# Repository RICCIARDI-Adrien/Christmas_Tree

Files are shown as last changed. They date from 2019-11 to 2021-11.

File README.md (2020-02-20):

# Christmas tree

A lighted Christmas tree with shiny fairy lights and star.  

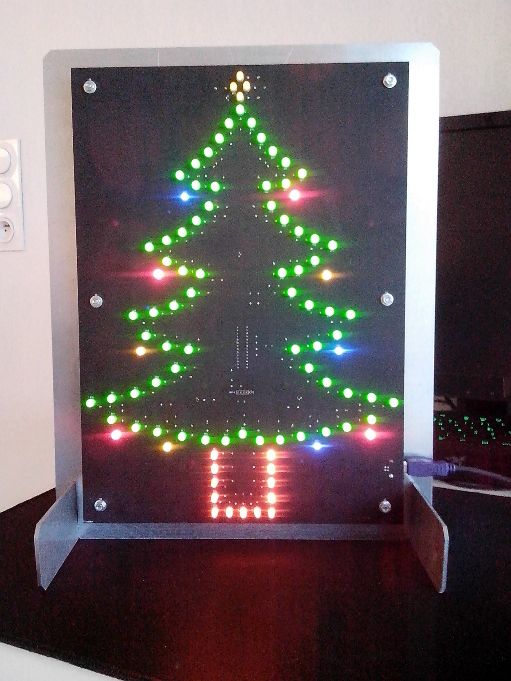
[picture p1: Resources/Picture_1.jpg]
Christmas tree picture 1

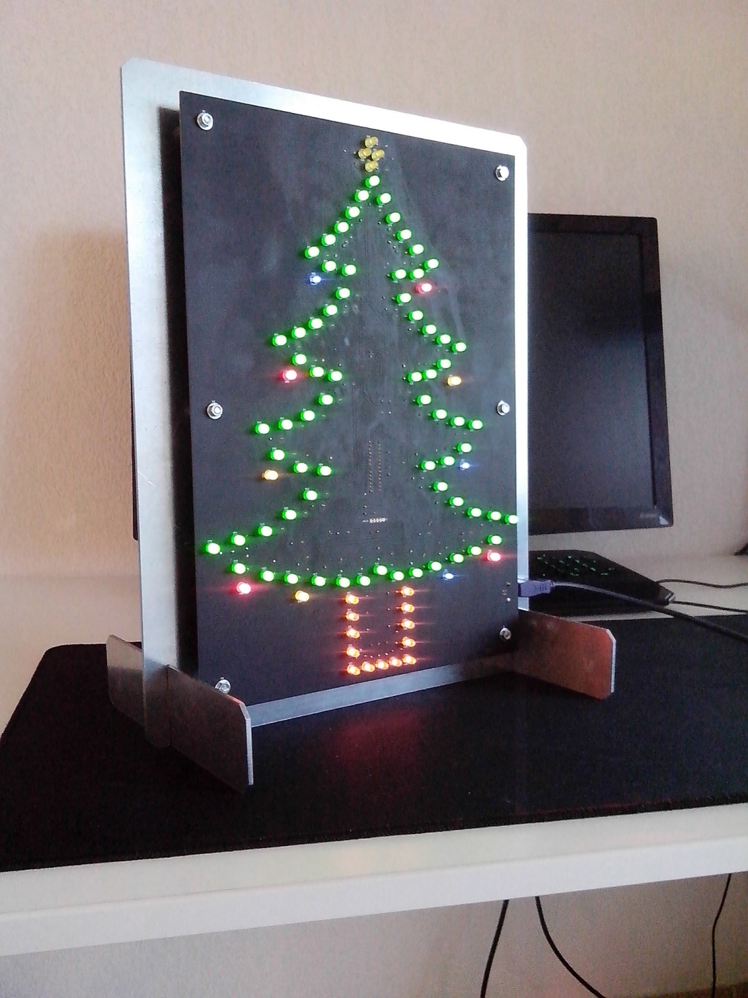
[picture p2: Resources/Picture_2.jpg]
Christmas tree picture 2


Here are all needed parts to build the Christmas tree :  
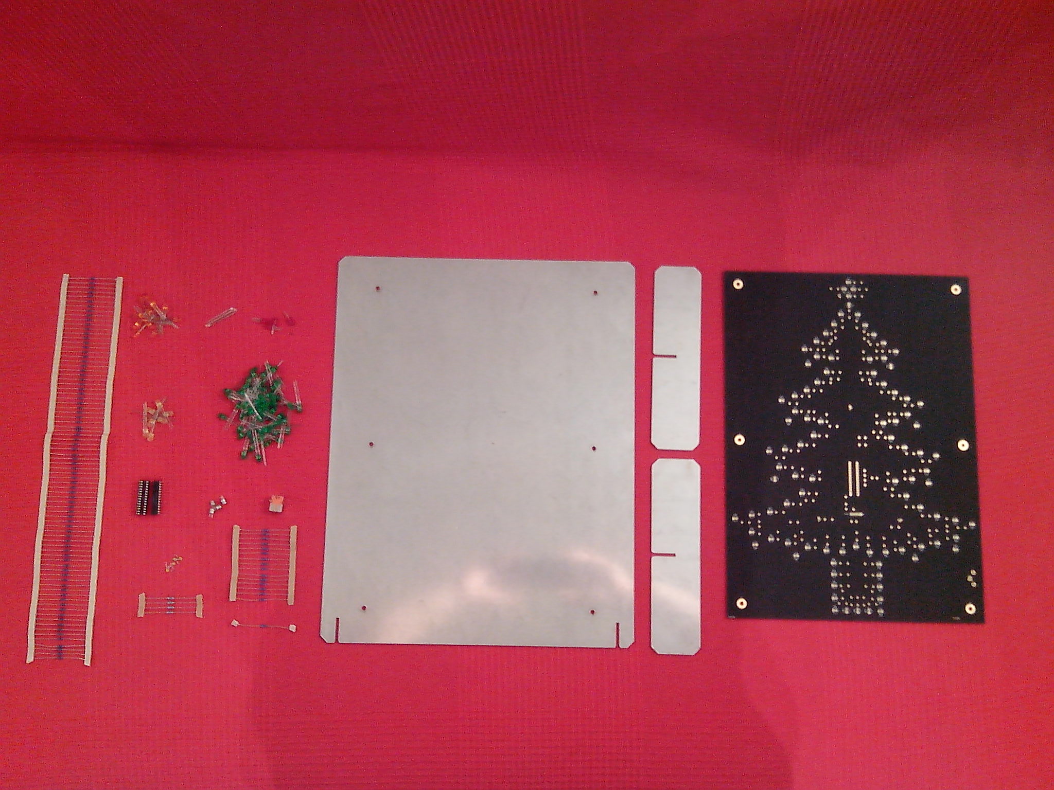
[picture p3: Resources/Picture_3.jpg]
Christmas tree picture 3


## Hardware

Board has been designed with KiCaD 5.1.4.
* PCB production files and Bill of materials are available in [releases](https://github.com/RICCIARDI-Adrien/Christmas_Tree/releases) section.
* When manufacturing the PCB, select a black top and bottom solder mask to highlight the leds.
* Board is powered by an USB-B connector. Use a 2A (or more) standard USB power supply, like [this one](https://fr.rs-online.com/web/p/adaptateurs-ac-dc/1242193/).

## Software

Software is written in C for Microchip XC8 compiler. It works with free compiler version.

To build the firmware, go to `Software` directory and type `make`.

## Casing

Casing and supports are made of 3mm-thick galvanized steel. A DXF file is provided in [releases](https://github.com/RICCIARDI-Adrien/Christmas_Tree/releases) section for laser cutting.

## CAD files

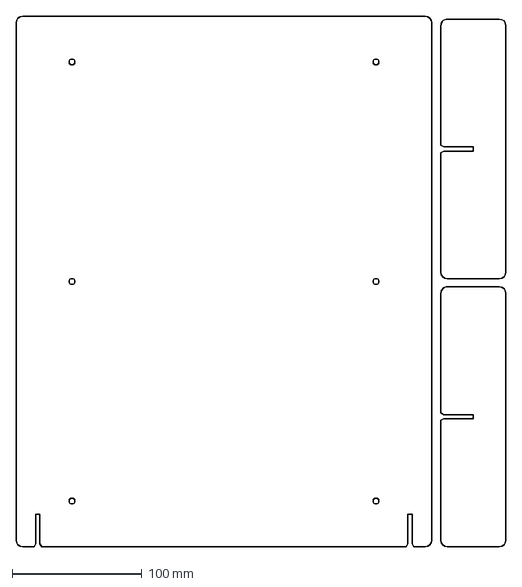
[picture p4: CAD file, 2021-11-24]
Casing/Casing_And_Parts.dxf
377.0 x 408.0 mm

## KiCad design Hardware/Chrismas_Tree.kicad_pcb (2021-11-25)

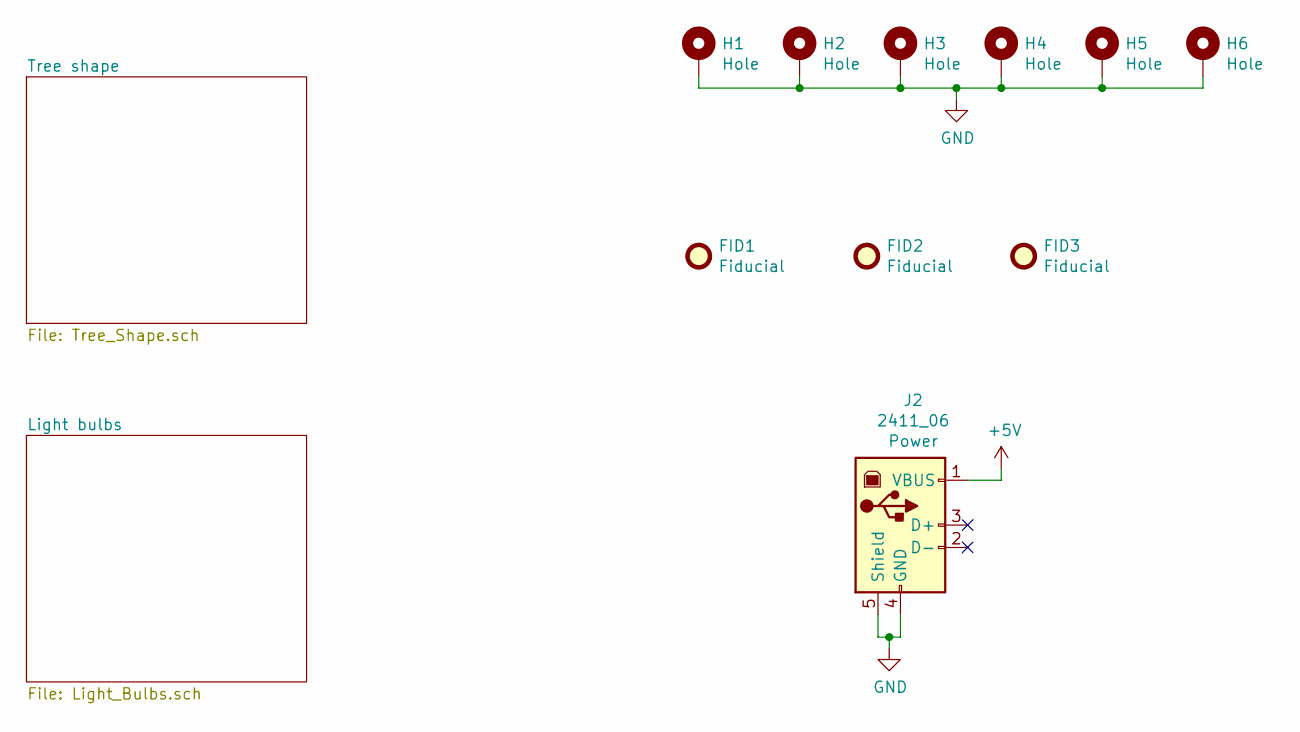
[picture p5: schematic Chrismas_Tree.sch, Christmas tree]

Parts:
FID1, FID2, FID3: Fiducial; Fiducial_1.5mm_Mask3mm
H1, H2, H3, H4, H5, H6: Hole; MountingHole_4.5mm_Pad
J2: 2411_06; USB_B_OST_USB-B1HSxx_Horizontal

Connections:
+5V: J2.1 (VBUS); also elsewhere on the board
GND: H1.1, H2.1, H3.1, H4.1, H5.1, H6.1, J2.4 (GND), J2.5 (Shield); also elsewhere on the board

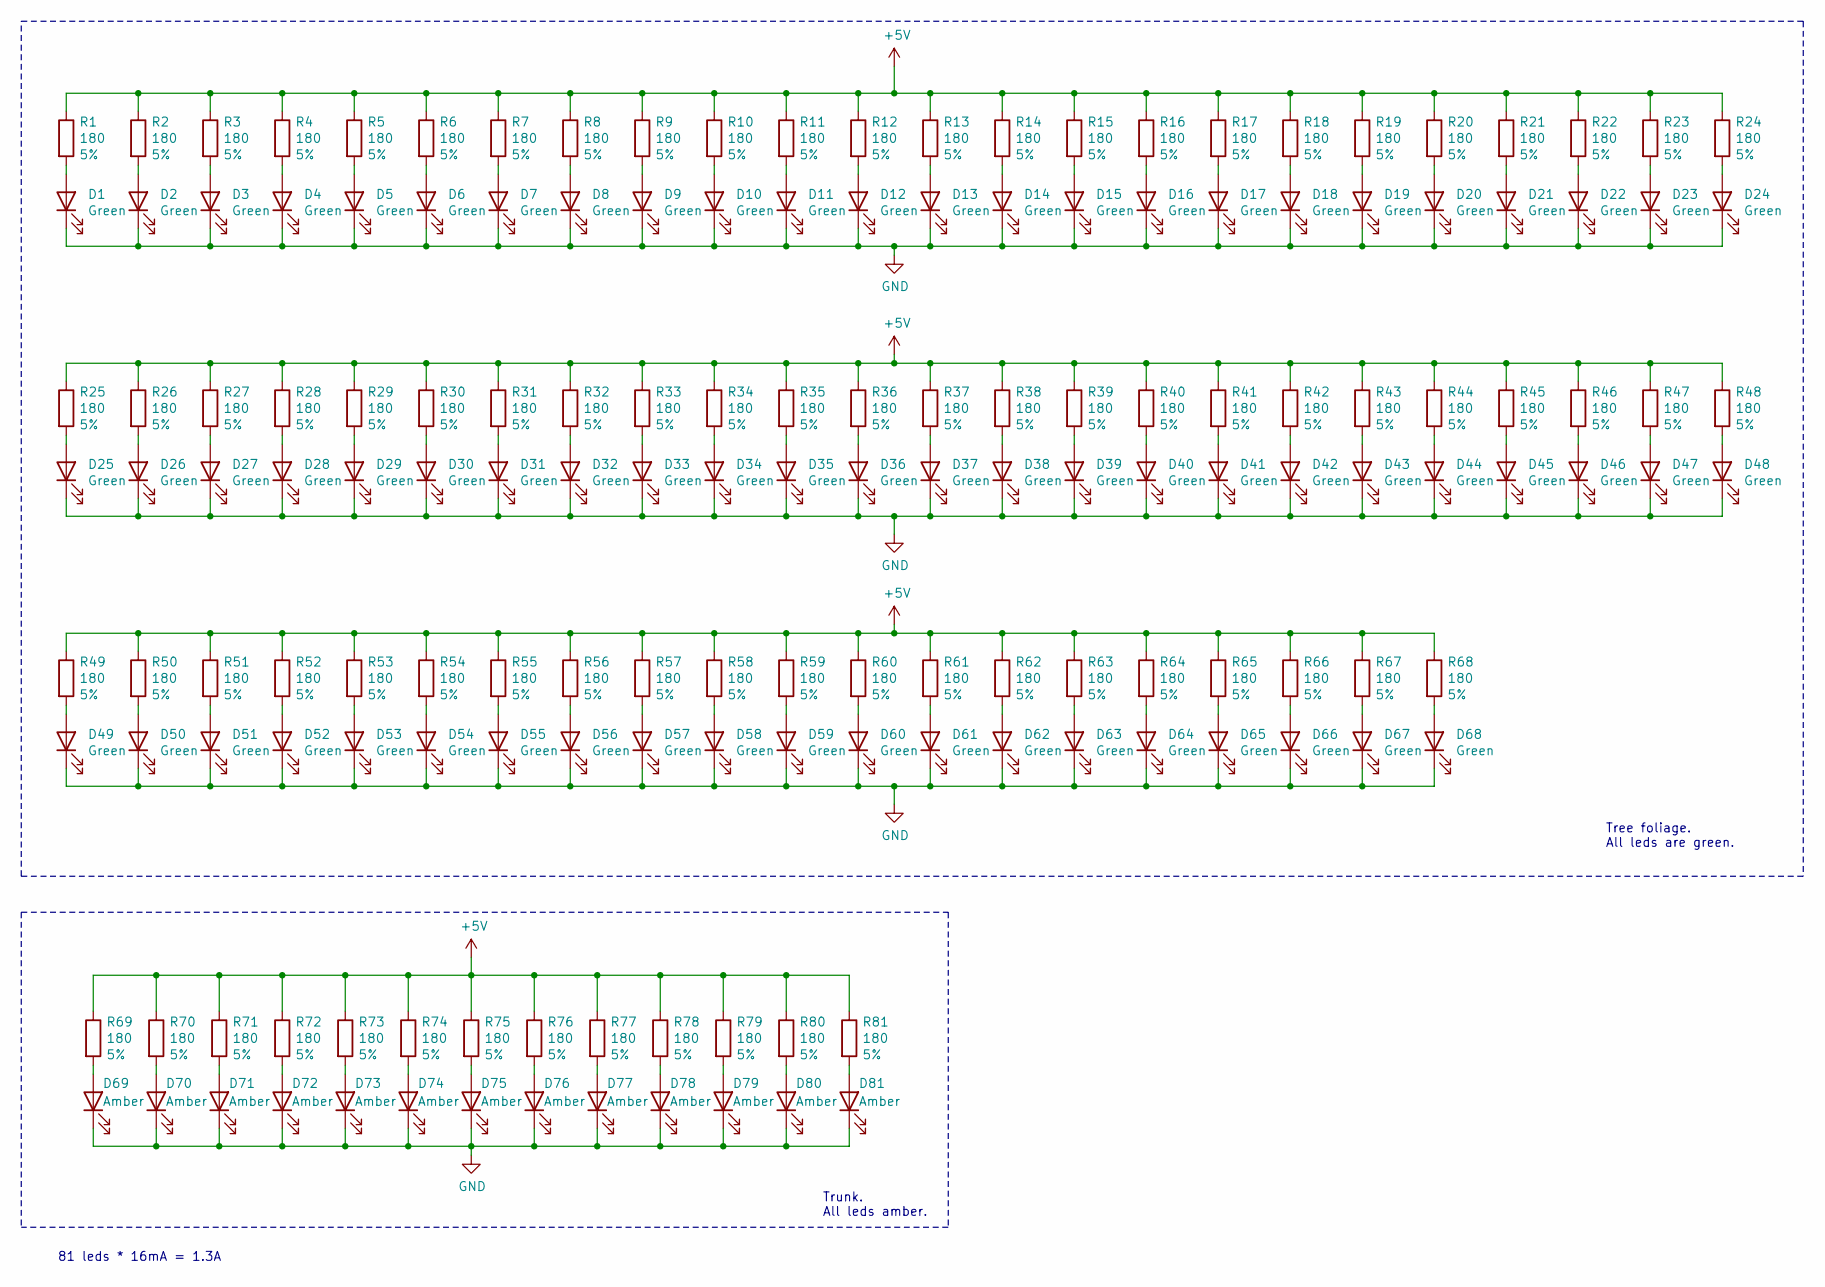
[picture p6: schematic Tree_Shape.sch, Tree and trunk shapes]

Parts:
D1, D2, D3, D4, D5, D6, D7, D8, D9, D10, D11, D12, D13, D14, D15, D16, D17, D18, D19, D20, D21, D22, D23, D24, D25, D26, D27, D28, D29, D30, D31, D32, D33, D34, D35, D36, D37, D38, D39, D40, D41, D42, D43, D44, D45, D46, D47, D48, D49, D50, D51, D52, D53, D54, D55, D56, D57, D58, D59, D60, D61, D62, D63, D64, D65, D66, D67, D68: Green; LED_D5.0mm
D69, D70, D71, D72, D73, D74, D75, D76, D77, D78, D79, D80, D81: Amber; LED_D5.0mm
R1, R2, R3, R4, R5, R6, R7, R8, R9, R10, R11, R12, R13, R14, R15, R16, R17, R18, R19, R20, R21, R22, R23, R24, R25, R26, R27, R28, R29, R30, R31, R32, R33, R34, R35, R36, R37, R38, R39, R40, R41, R42, R43, R44, R45, R46, R47, R48, R49, R50, R51, R52, R53, R54, R55, R56, R57, R58, R59, R60, R61, R62, R63, R64, R65, R66, R67, R68, R69, R70, R71, R72, R73, R74, R75, R76, R77, R78, R79, R80, R81: 180; R_1206_3216Metric_Pad1.30x1.75mm_HandSolder

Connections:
+5V: R1.1, R2.1, R3.1, R4.1, R5.1, R6.1, R7.1, R8.1, R9.1, R10.1, R11.1, R12.1, R13.1, R14.1, R15.1, R16.1, R17.1, R18.1, R19.1, R20.1, R21.1, R22.1, R23.1, R24.1, R25.1, R26.1, R27.1, R28.1, R29.1, R30.1, R31.1, R32.1, R33.1, R34.1, R35.1, R36.1, R37.1, R38.1, R39.1, R40.1, R41.1, R42.1, R43.1, R44.1, R45.1, R46.1, R47.1, R48.1, R49.1, R50.1, R51.1, R52.1, R53.1, R54.1, R55.1, R56.1, R57.1, R58.1, R59.1, R60.1, R61.1, R62.1, R63.1, R64.1, R65.1, R66.1, R67.1, R68.1, R69.1, R70.1, R71.1, R72.1, R73.1, R74.1, R75.1, R76.1, R77.1, R78.1, R79.1, R80.1, R81.1; also elsewhere on the board
GND: D1.1 (K), D2.1 (K), D3.1 (K), D4.1 (K), D5.1 (K), D6.1 (K), D7.1 (K), D8.1 (K), D9.1 (K), D10.1 (K), D11.1 (K), D12.1 (K), D13.1 (K), D14.1 (K), D15.1 (K), D16.1 (K), D17.1 (K), D18.1 (K), D19.1 (K), D20.1 (K), D21.1 (K), D22.1 (K), D23.1 (K), D24.1 (K), D25.1 (K), D26.1 (K), D27.1 (K), D28.1 (K), D29.1 (K), D30.1 (K), D31.1 (K), D32.1 (K), D33.1 (K), D34.1 (K), D35.1 (K), D36.1 (K), D37.1 (K), D38.1 (K), D39.1 (K), D40.1 (K), D41.1 (K), D42.1 (K), D43.1 (K), D44.1 (K), D45.1 (K), D46.1 (K), D47.1 (K), D48.1 (K), D49.1 (K), D50.1 (K), D51.1 (K), D52.1 (K), D53.1 (K), D54.1 (K), D55.1 (K), D56.1 (K), D57.1 (K), D58.1 (K), D59.1 (K), D60.1 (K), D61.1 (K), D62.1 (K), D63.1 (K), D64.1 (K), D65.1 (K), D66.1 (K), D67.1 (K), D68.1 (K), D69.1 (K), D70.1 (K), D71.1 (K), D72.1 (K), D73.1 (K), D74.1 (K), D75.1 (K), D76.1 (K), D77.1 (K), D78.1 (K), D79.1 (K), D80.1 (K), D81.1 (K); also elsewhere on the board
unnamed: D1.2 (A), R1.2
unnamed: D2.2 (A), R2.2
unnamed: D3.2 (A), R3.2
unnamed: D4.2 (A), R4.2
unnamed: D5.2 (A), R5.2
unnamed: D6.2 (A), R6.2
unnamed: D7.2 (A), R7.2
unnamed: D8.2 (A), R8.2
unnamed: D9.2 (A), R9.2
unnamed: D10.2 (A), R10.2
unnamed: D11.2 (A), R11.2
unnamed: D12.2 (A), R12.2
unnamed: D13.2 (A), R13.2
unnamed: D14.2 (A), R14.2
unnamed: D15.2 (A), R15.2
unnamed: D16.2 (A), R16.2
unnamed: D17.2 (A), R17.2
unnamed: D18.2 (A), R18.2
unnamed: D19.2 (A), R19.2
unnamed: D20.2 (A), R20.2
unnamed: D21.2 (A), R21.2
unnamed: D22.2 (A), R22.2
unnamed: D23.2 (A), R23.2
unnamed: D24.2 (A), R24.2
unnamed: D25.2 (A), R25.2
unnamed: D26.2 (A), R26.2
unnamed: D27.2 (A), R27.2
unnamed: D28.2 (A), R28.2
unnamed: D29.2 (A), R29.2
unnamed: D30.2 (A), R30.2
unnamed: D31.2 (A), R31.2
unnamed: D32.2 (A), R32.2
unnamed: D33.2 (A), R33.2
unnamed: D34.2 (A), R34.2
unnamed: D35.2 (A), R35.2
unnamed: D36.2 (A), R36.2
unnamed: D37.2 (A), R37.2
unnamed: D38.2 (A), R38.2
unnamed: D39.2 (A), R39.2
unnamed: D40.2 (A), R40.2
unnamed: D41.2 (A), R41.2
unnamed: D42.2 (A), R42.2
unnamed: D43.2 (A), R43.2
unnamed: D44.2 (A), R44.2
unnamed: D45.2 (A), R45.2
unnamed: D46.2 (A), R46.2
unnamed: D47.2 (A), R47.2
unnamed: D48.2 (A), R48.2
unnamed: D49.2 (A), R49.2
unnamed: D50.2 (A), R50.2
unnamed: D51.2 (A), R51.2
unnamed: D52.2 (A), R52.2
unnamed: D53.2 (A), R53.2
unnamed: D54.2 (A), R54.2
unnamed: D55.2 (A), R55.2
unnamed: D56.2 (A), R56.2
unnamed: D57.2 (A), R57.2
unnamed: D58.2 (A), R58.2
unnamed: D59.2 (A), R59.2
unnamed: D60.2 (A), R60.2
unnamed: D61.2 (A), R61.2
unnamed: D62.2 (A), R62.2
unnamed: D63.2 (A), R63.2
unnamed: D64.2 (A), R64.2
unnamed: D65.2 (A), R65.2
unnamed: D66.2 (A), R66.2
unnamed: D67.2 (A), R67.2
unnamed: D68.2 (A), R68.2
unnamed: D69.2 (A), R69.2
unnamed: D70.2 (A), R70.2
unnamed: D71.2 (A), R71.2
unnamed: D72.2 (A), R72.2
unnamed: D73.2 (A), R73.2
unnamed: D74.2 (A), R74.2
unnamed: D75.2 (A), R75.2
unnamed: D76.2 (A), R76.2
unnamed: D77.2 (A), R77.2
unnamed: D78.2 (A), R78.2
unnamed: D79.2 (A), R79.2
unnamed: D80.2 (A), R80.2
unnamed: D81.2 (A), R81.2

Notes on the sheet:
Tree foliage. All leds are green.
Trunk. All leds amber.
81 leds * 16mA = 1.3A

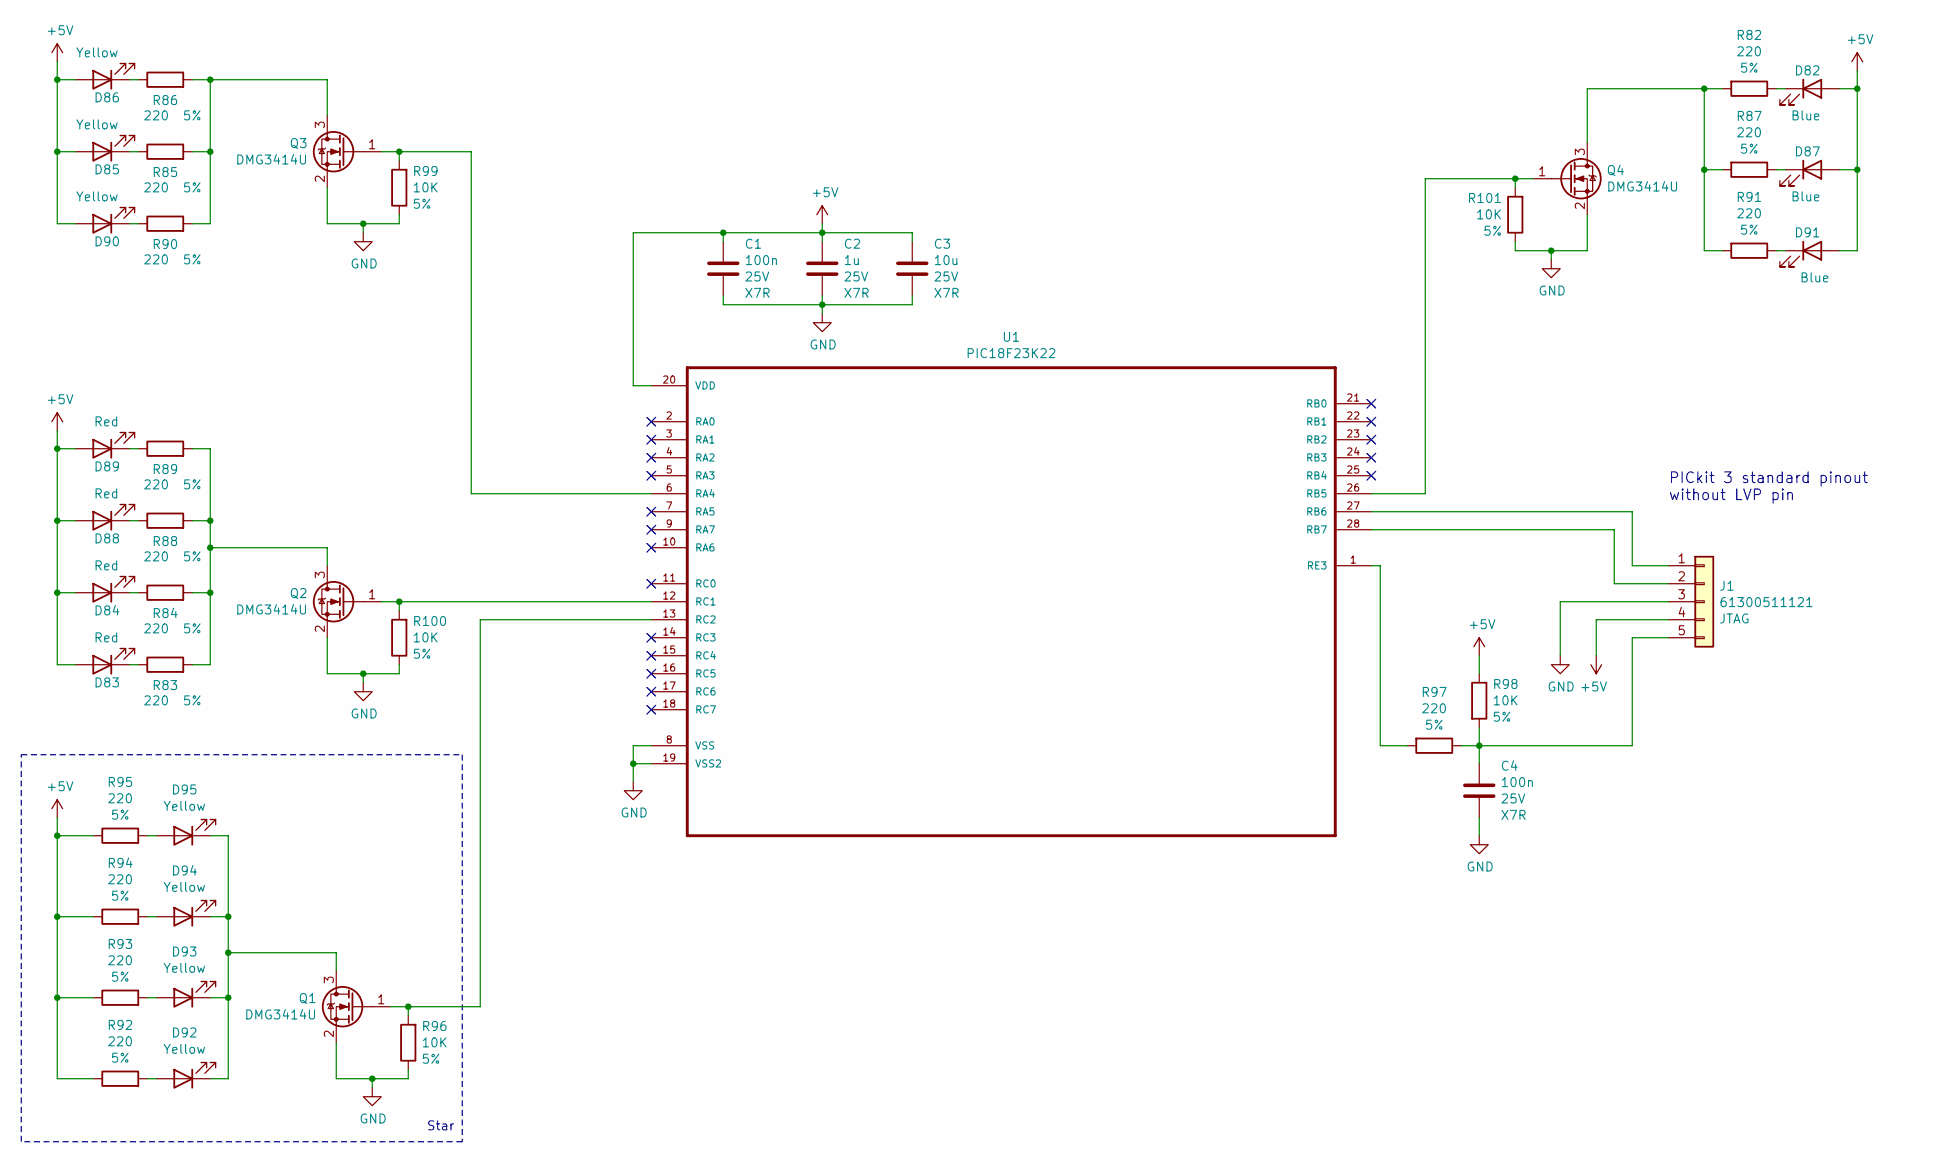
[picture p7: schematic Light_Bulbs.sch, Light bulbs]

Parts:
C1, C4: 100n; C_1206_3216Metric_Pad1.33x1.80mm_HandSolder
C2: 1u; C_1206_3216Metric_Pad1.33x1.80mm_HandSolder
C3: 10u; C_1206_3216Metric_Pad1.33x1.80mm_HandSolder
D82, D87, D91: Blue; LED_D5.0mm
D83, D84, D88, D89: Red; LED_D5.0mm
D85, D86, D90, D92, D93, D94, D95: Yellow; LED_D5.0mm
J1: 61300511121; PinHeader_1x05_P2.54mm_Vertical
Q1, Q2, Q3, Q4: DMG3414U; SOT-23
R82, R83, R84, R85, R86, R87, R88, R89, R90, R91, R92, R93, R94, R95, R97: 220; R_1206_3216Metric_Pad1.30x1.75mm_HandSolder
R96, R98, R99, R100, R101: 10K; R_1206_3216Metric_Pad1.30x1.75mm_HandSolder
U1: PIC18F23K22; SOIC-28W_7.5x17.9mm_P1.27mm

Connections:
+5V: C1.1, C2.1, C3.1, D82.2 (A), D83.2 (A), D84.2 (A), D85.2 (A), D86.2 (A), D87.2 (A), D88.2 (A), D89.2 (A), D90.2 (A), D91.2 (A), J1.4, R92.1, R93.1, R94.1, R95.1, R98.1, U1.20 (VDD); also elsewhere on the board
GND: C1.2, C2.2, C3.2, C4.2, J1.3, Q1.2 (S), Q2.2 (S), Q3.2 (S), Q4.2 (S), R96.1, R99.1, R100.1, R101.1, U1.8 (VSS), U1.19 (VSS2); also elsewhere on the board
unnamed: C4.1, J1.5, R97.1, R98.2
unnamed: D82.1 (K), R82.1
unnamed: D83.1 (K), R83.1
unnamed: D84.1 (K), R84.1
unnamed: D85.1 (K), R85.1
unnamed: D86.1 (K), R86.1
unnamed: D87.1 (K), R87.1
unnamed: D88.1 (K), R88.1
unnamed: D89.1 (K), R89.1
unnamed: D90.1 (K), R90.1
unnamed: D91.1 (K), R91.1
unnamed: D92.1 (K), D93.1 (K), D94.1 (K), D95.1 (K), Q1.3 (D)
unnamed: D92.2 (A), R92.2
unnamed: D93.2 (A), R93.2
unnamed: D94.2 (A), R94.2
unnamed: D95.2 (A), R95.2
unnamed: J1.1, U1.27 (RB6)
unnamed: J1.2, U1.28 (RB7)
unnamed: Q1.1 (G), R96.2, U1.13 (RC2)
unnamed: Q2.1 (G), R100.2, U1.12 (RC1)
unnamed: Q2.3 (D), R83.2, R84.2, R88.2, R89.2
unnamed: Q3.1 (G), R99.2, U1.6 (RA4)
unnamed: Q3.3 (D), R85.2, R86.2, R90.2
unnamed: Q4.1 (G), R101.2, U1.26 (RB5)
unnamed: Q4.3 (D), R82.2, R87.2, R91.2
unnamed: R97.2, U1.1 (RE3)

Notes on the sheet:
PICkit 3 standard pinout without LVP pin
Star

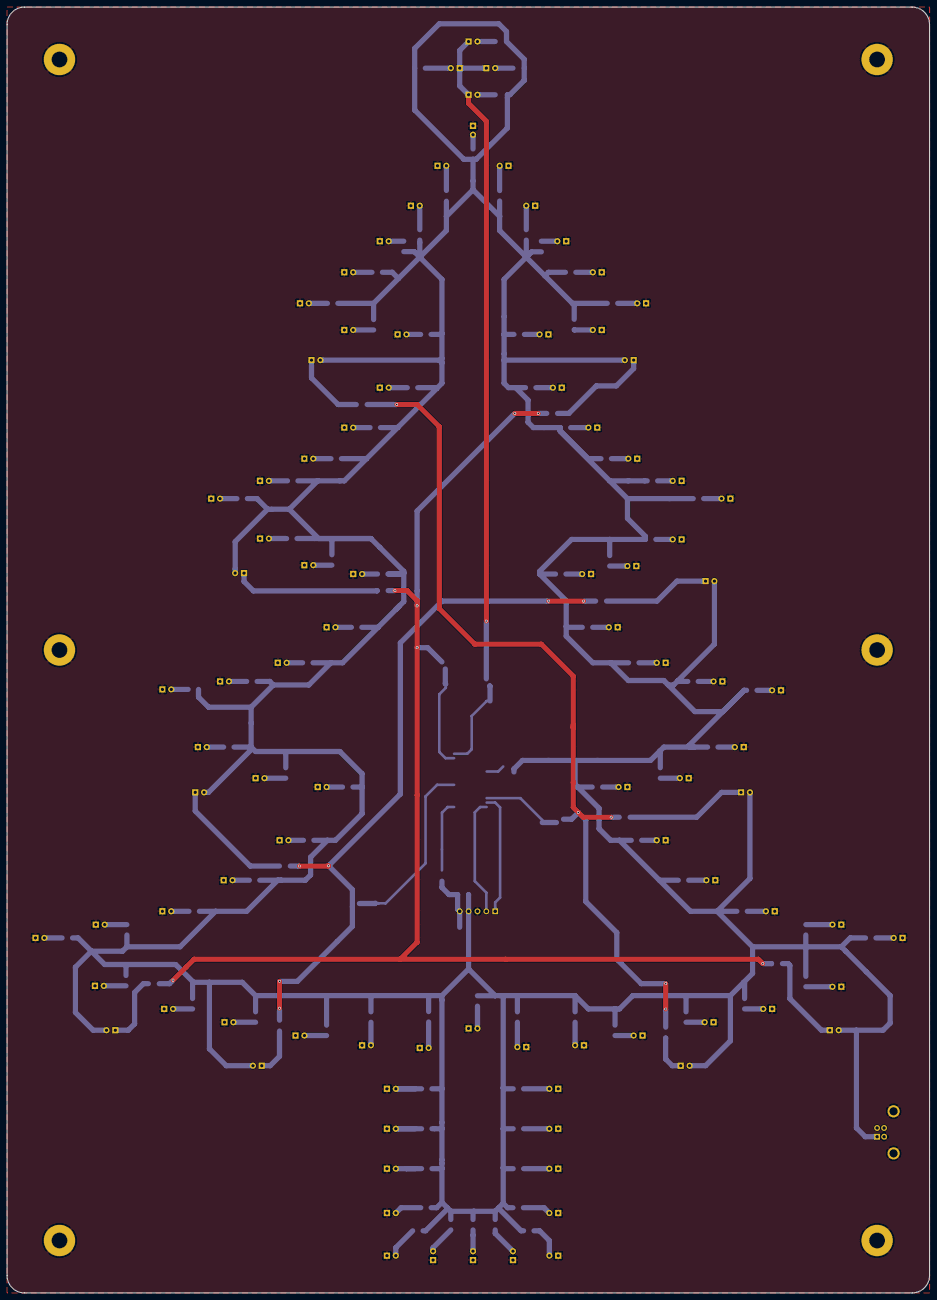
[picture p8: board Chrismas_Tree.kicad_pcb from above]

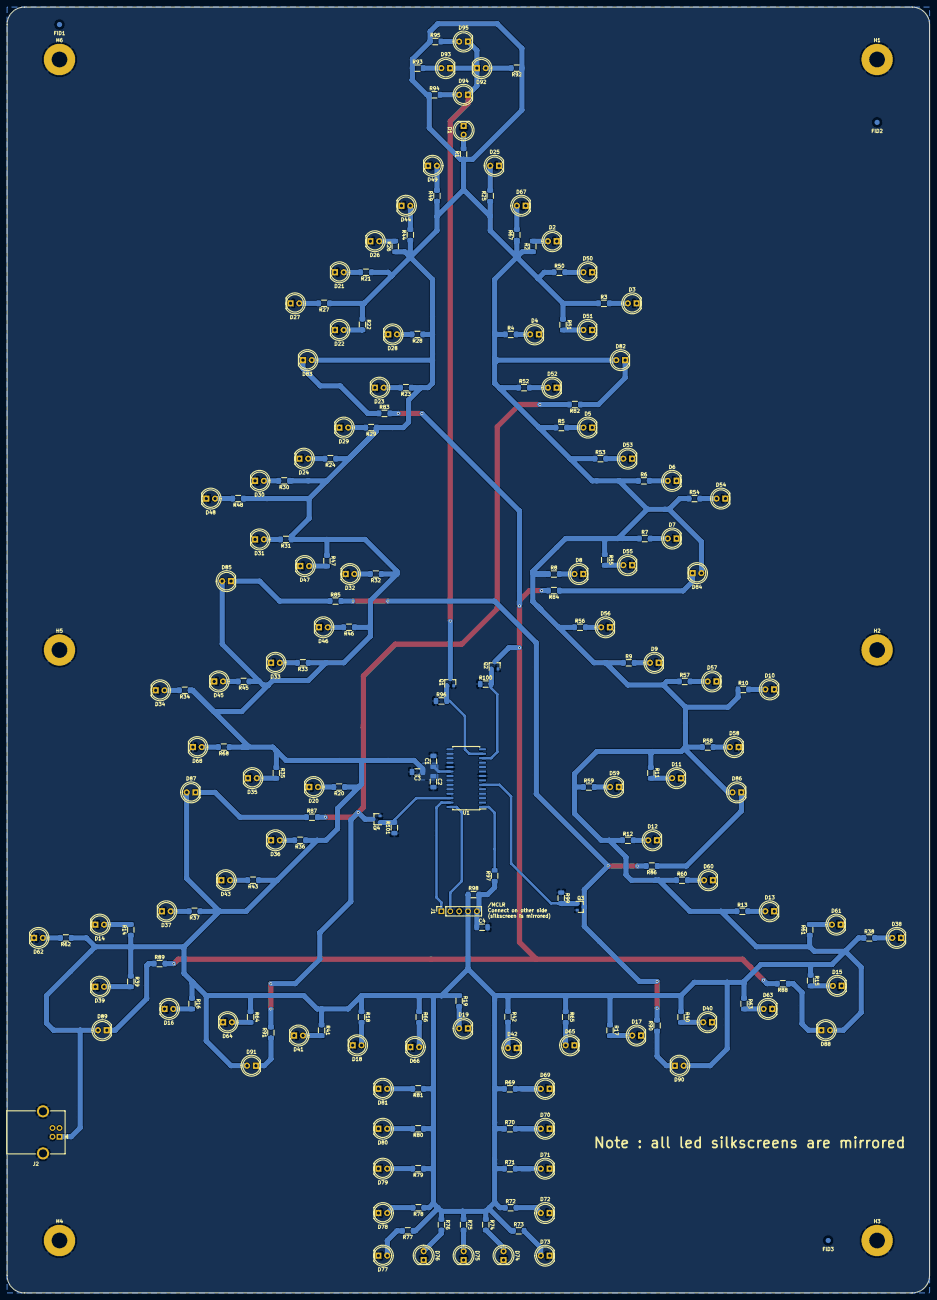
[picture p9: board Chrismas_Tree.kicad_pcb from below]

Board: 2 copper layers, 264.0 x 368.0 mm, 216 parts (114 on the bottom side), 109 nets.

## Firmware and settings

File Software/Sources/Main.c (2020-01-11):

/** @file Main.c
 * Handle light bulbs fading cycles.
 * @author Adrien RICCIARDI
 */
#include <PWM.h>
#include <xc.h>

//-------------------------------------------------------------------------------------------------
// Microcontroller configuration
//-------------------------------------------------------------------------------------------------
// CONFIG1H register
#pragma config FOSC = INTIO67, PLLCFG = OFF, PRICLKEN = ON, FCMEN = OFF, IESO = OFF // Use internal oscillator, do not enable PLL, enable primary clock, disable fail-safe clock monitor, disable oscillator switchover mode
// CONFIG2L register
#pragma config PWRTEN = ON, BOREN = SBORDIS, BORV = 285 // Enable power up timer, enable brown-out reset in hardware only (so it can't be disabled by software), set highest value for brown-out voltage (2.85V)
// CONFIG2H register
#pragma config WDTEN = OFF // Disable watchdog timer
// CONFIG3H register
#pragma config CCP2MX = PORTC1, PBADEN = OFF, CCP3MX = PORTB5, HFOFST = OFF, MCLRE = EXTMCLR // Connect CCP2 module to RC1 pin, port B pin 5..0 are configured as digital I/O on reset, connect CCP3 module to RB5 pin, wait for the oscillator to become stable before starting executing code, enable MCLR pin
// CONFIG4L register
#pragma config STVREN = ON, LVP = OFF, XINST = OFF, DEBUG = OFF // Reset on stack underflow or overflow, disable single supply ICSP, disable extended instruction set, disable background debug
// CONFIG5L register
#pragma config CP0 = OFF, CP1 = OFF // Disable all code protections
// CONFIG5H register
#pragma config CPB = OFF, CPD = OFF // Disable boot block code protection, disable data EEPROM code protection
// CONFIG6L register
#pragma config WRT0 = OFF, WRT1 = OFF // Disable all write protections
// CONFIG6H register
#pragma config WRTC = OFF, WRTB = OFF, WRTD = OFF // Disable configuration registers write protection, disable boot block write protection, disable data EEPROM write protection
// CONFIG7L register
#pragma config EBTR0 = OFF, EBTR1 = OFF // Disable all table read protections
// CONFIG7H register
#pragma config EBTRB = OFF // Disable boot block table read protection

//-------------------------------------------------------------------------------------------------
// Private constants
//-------------------------------------------------------------------------------------------------
/** How many steps in the dimming curve. */
#define MAIN_DIMMING_VALUES_COUNT (sizeof(Main_Dimming_Values) / sizeof(Main_Dimming_Values[0]))

//-------------------------------------------------------------------------------------------------
// Private types
//-------------------------------------------------------------------------------------------------
/** Allow to shine each led separately. */
typedef struct
{
	unsigned char Dimming_Value_Index; //!< How bright the led must be lighted.
	unsigned char Is_Index_Incrementing; //!< Tell whether led brightness must increase or decrease.
} TMainShiningLed;

//-------------------------------------------------------------------------------------------------
// Private variables
//-------------------------------------------------------------------------------------------------
/** All the leds that will shine. */
static TMainShiningLed Main_Shining_Leds[PWM_CHANNEL_IDS_COUNT] =
{
	// PWM_CHANNEL_ID_STAR
	{
		0,
		1
	},
	// PWM_CHANNEL_ID_RED_FAIRY_LIGHTS
	{
		16,
		1
	},
	// PWM_CHANNEL_ID_BLUE_FAIRY_LIGHTS
	{
		32,
		1
	},
	// PWM_CHANNEL_ID_YELLOW_FAIRY_LIGHTS
	{
		48,
		1
	}
};

/** Exponential lookup table, computed to make the brightness variations linear to an human eye.
 * See Leds_Dimming_Lookup_Table.ods document in repository Resources directory for details about its computation.
 */
static unsigned short Main_Dimming_Values[] =
{
	   0,    0,    1,    2,    3,    4,    5,    7,    8,   10,
	  12,   15,   17,   20,   23,   26,   30,   33,   37,   41,
	  45,   50,   54,   59,   64,   69,   75,   80,   86,   92,
	  98,  105,  111,  118,  125,  133,  140,  148,  156,  164,
	 172,  180,  189,  198,  207,  216,  226,  236,  246,  256,
	 266,  277,  287,  298,  309,  321,  332,  344,  356,  368,
	 381,  393,  406,  419,  432,  446,  459,  473,  487,  501,
	 516,  530,  545,  560,  575,  591,  607,  622,  638,  655,
	 671,  688,  705,  722,  739,  757,  774,  792,  810,  829,
	 847,  866,  885,  904,  923,  943,  963,  982, 1003, 1023
};

//-------------------------------------------------------------------------------------------------
// Entry point
//-------------------------------------------------------------------------------------------------
void main(void)
{
	unsigned char i;
	TMainShiningLed *Pointer_Shining_Led;
	
	// Set oscillator frequency to 4MHz
	OSCCON = 0x52; // Set a 4MHz internal oscillator frequency, select internal oscillator block
	
	// Initialize all modules
	PWMInitialize();

	// Make fairy lights and star shine
	while (1)
	{
		// Handle all leds
		for (i = 0; i < PWM_CHANNEL_IDS_COUNT; i++)
		{
			// Cache led access
			Pointer_Shining_Led = &Main_Shining_Leds[i];
			
			// Set current led brightness
			PWMSetDutyCycle(i, Main_Dimming_Values[Pointer_Shining_Led->Dimming_Value_Index]);
			
			// Update value index
			if (Pointer_Shining_Led->Is_Index_Incrementing)
			{
				// Keep incrementing
				Pointer_Shining_Led->Dimming_Value_Index++;
				// Prepare for decrementing next time if last dimming value has been reached
				if (Pointer_Shining_Led->Dimming_Value_Index >= MAIN_DIMMING_VALUES_COUNT - 1) Pointer_Shining_Led->Is_Index_Incrementing = 0;
			}
			else
			{
				// Keep decrementing
				Pointer_Shining_Led->Dimming_Value_Index--;
				// Prepare for incrementing next time if first dimming value has been reached
				if (Pointer_Shining_Led->Dimming_Value_Index == 0) Pointer_Shining_Led->Is_Index_Incrementing = 1;
			}
		}
		
		// Keep led brightness a little
		__delay_ms(80);
	}
}

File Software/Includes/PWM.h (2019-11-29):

/** @file PWM.h
 * Manage 4 separate PWM channels, one for each tree fading block.
 * @author Adrien RICCIARDI
 */
#ifndef H_PWM_H
#define H_PWM_H

//-------------------------------------------------------------------------------------------------
// Constants
//-------------------------------------------------------------------------------------------------
/** Maximum PWM duty cycle period. When setting this period, the PWM pin is always set. */
#define PWM_MAXIMUM_DUTY_CYCLE_VALUE 1023

//-------------------------------------------------------------------------------------------------
// Types
//-------------------------------------------------------------------------------------------------
/** All available channels. */
typedef enum
{
	PWM_CHANNEL_ID_STAR, // Use CCP1 module on RC2 pin
	PWM_CHANNEL_ID_RED_FAIRY_LIGHTS, // Use CCP2 module on RC1 pin
	PWM_CHANNEL_ID_BLUE_FAIRY_LIGHTS, // Use CCP3 module on RB5 pin
	PWM_CHANNEL_ID_YELLOW_FAIRY_LIGHTS, // Use CCP5 module on RA4 pin
	PWM_CHANNEL_IDS_COUNT
} TPWMChannelID;

//-------------------------------------------------------------------------------------------------
// Functions
//-------------------------------------------------------------------------------------------------
/** Initialize all PWM channels and start producing signals. */
void PWMInitialize(void);

/** Set a specific channel duty cycle period.
 * @param Channel_ID The channel to configure.
 * @param Duty_Cycle_Period How many time the channel pin remains set. Setting value 0 makes the pin stay always low, setting value PWM_MAXIMUM_DUTY_CYCLE_VALUE makes the pin stay always high.
 */
void PWMSetDutyCycle(TPWMChannelID Channel_ID, unsigned short Duty_Cycle_Period);

#endif

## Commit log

2019-11-27 Initial commit. Added tree leds to schematic and designed tree shape on PCB.
    [Chrismas_Tree.kicad_pcb, Chrismas_Tree.sch]
2019-11-27 Added tree trunk to schematic and PCB.
    [Chrismas_Tree.kicad_pcb, Chrismas_Tree.sch]
2019-11-27 Reorganized schematic to use several sheets.
    [Chrismas_Tree.kicad_pcb, Chrismas_Tree.sch, Light_Bulbs.sch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]
2019-11-27 Added microcontroller symbol and footprint.
    [Chrismas_Tree.kicad_pcb, Light_Bulbs.sch]
2019-11-27 Placed all tree foliage and trunk resistors on the PCB.
    [Chrismas_Tree.kicad_pcb]
2019-11-27 Moved hardware files directly to Hardware directory for more coherency.
    [Chrismas_Tree.kicad_pcb, Chrismas_Tree.sch, Light_Bulbs.sch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]
2019-11-27 Added light bulbs schematic.
    [Chrismas_Tree.kicad_pcb, Light_Bulbs.sch, Tree_Shape.sch]
2019-11-27 Reorganized light bulbs connections to ease routing and placed microcontroller and related parts.
    [Chrismas_Tree.kicad_pcb, Light_Bulbs.sch]
2019-11-27 Set foliage and trunk leds color.
    [Chrismas_Tree.kicad_pcb, Tree_Shape.sch]
2019-11-27 Set foliage leds resistors value.
    [Tree_Shape.sch]
2019-11-27 Set trunk leds resistors value.
    [Tree_Shape.sch]
2019-11-27 Added micro USB B connector for power supply.
    [Chrismas_Tree.kicad_pcb, Light_Bulbs.sch]
2019-11-27 Routed whole circuit and added ground planes.
    [Chrismas_Tree.kicad_pcb, Light_Bulbs.sch, Tree_Shape.sch]
2019-11-28 Used standard schematic title blocks titles.
    [Chrismas_Tree.sch, Light_Bulbs.sch, Tree_Shape.sch]
2019-11-28 Fixed PCB title block.
    [Chrismas_Tree.kicad_pcb]
2019-11-28 Added PCB edges cut.
    [Chrismas_Tree.kicad_pcb]
2019-11-28 Resized board to center the tree in the PCB middle.
    [Chrismas_Tree.kicad_pcb]
2019-11-28 Adjusted bottom left branch light bulbs.
    [Chrismas_Tree.kicad_pcb]
2019-11-28 Added fixation holes to PCB.
    [Chrismas_Tree.kicad_pcb]
2019-11-28 Increased transitor base resistor value.
    [Chrismas_Tree.kicad_pcb, Chrismas_Tree.sch, Light_Bulbs.sch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]
2019-11-28 Started firmware implementation. A led is blinking.
2019-11-28 Started software PWM implementation. Added working test to access through pointer to port register.
2019-11-28 Added PWM base frequency generation.
2019-11-28 Added working software PWM.
2019-11-28 Added the ability to set PWM duty cycle period.
2019-11-28 Initialized all PWM channels in Fading Leds module.
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2019-11-29 Added mounting holes to schematic.
    [Chrismas_Tree.kicad_pcb, Chrismas_Tree.sch]
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2019-11-29 Updated schematic and PCB to use microcontroller hardware PWMs to control fairy lights by color and star instead of all light bulbs separately.
    [Chrismas_Tree.kicad_pcb, Light_Bulbs.sch]
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2019-11-29 Added some phase difference between each PWM channel to make each channel blink separately.
2019-11-30 Replaced USB micro B connector by a more robust USB B one.
    [Chrismas_Tree.kicad_pcb, Chrismas_Tree.sch, Light_Bulbs.sch]
2019-11-30 Made sure all leds are turned off at boot.
2019-11-30 Added casing drawing. This is not the production file to send to laser cutter because it contains PCB and flat square brackets parts.
    [Casing_And_Parts.dxf]
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2019-12-06 Replaced leds linear brightness variation by an exponential one to make dimming feels more linear to human eye.
    [Main.c]
2019-12-07 Removed flat angle brackets and added supports to casing.
    [Casing_And_Parts.dxf]
2019-12-08 Decreased casing supports height to avoid obstructing USB connector.
    [Casing_And_Parts.dxf]
2020-01-02 Decreased casing grooves thickness to decrease play between supports and casing.
    [Casing_And_Parts.dxf]
2020-01-11 Improved leds dimming by using a dimming equation better matching human eye response.
    [Leds_Dimming_Lookup_Table.ods]
2020-06-13 Replaced light bulb through-hole resistors by SMD ones.
    [Chrismas_Tree.kicad_pcb, Chrismas_Tree.sch, Light_Bulbs.sch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]
2020-06-17 Put all amber leds in their right place.
    [Chrismas_Tree.kicad_pcb]
2020-06-17 Replaced trunk through-hole resistors by SMD ones.
    [Chrismas_Tree.kicad_pcb, Tree_Shape.sch]
2020-09-18 Changed PCB copper area isolation to get a better filling.
    [Chrismas_Tree.kicad_pcb]
2020-09-18 Turned rotated leds to have all them on the same axis (but trunk base ones).
    [Chrismas_Tree.kicad_pcb]
2020-09-18 Replaced tree foliage through-hole resistors by SMD ones.
    [Chrismas_Tree.kicad_pcb, Tree_Shape.sch]
2020-09-18 Replaced though-hole capacitors by SMD ones.
    [Chrismas_Tree.kicad_pcb, Light_Bulbs.sch]
2020-09-18 Replaced through-hole transistors by SMD ones.
    [Chrismas_Tree.kicad_pcb, Light_Bulbs.sch]
2020-09-18 Changed microcontroller package for a SMD one.
    [Chrismas_Tree.kicad_pcb, Light_Bulbs.sch]
2020-09-18 Added rounded corners to PCB, improved PCB dimensions to fit in millimeters.
    [Chrismas_Tree.kicad_pcb]
2021-11-21 Updated USB connector symbol reference in schematic to conform to KiCad 5.1.10.
    [Chrismas_Tree.sch]
2021-11-21 Added USB connector 3D model to PCB.
    [Chrismas_Tree.kicad_pcb]
2021-11-21 Moved mounting holes silkscreen text to bottom layer, so it is not shown on the leds side.
    [Chrismas_Tree.kicad_pcb]
2021-11-21 Reset PCB solder mask settings as default ones work fine.
2021-11-21 Changed all remaining through-hole resistors by SMD ones in both schematic and PCB.
    [Chrismas_Tree.kicad_pcb, Light_Bulbs.sch]
2021-11-21 Converted all 1206 SMD footprints to KiCad 5.1.10 latest one in both schematic and PCB.
    [Chrismas_Tree.kicad_pcb, Light_Bulbs.sch, Tree_Shape.sch]
2021-11-21 Moved all PCB top layer silkscreen texts to bottom layer.
    [Chrismas_Tree.kicad_pcb]
2021-11-21 Updated bill of materials data on schematic to improve generated bill of materials.
    [Chrismas_Tree.sch, Light_Bulbs.sch, Tree_Shape.sch]
2021-11-21 Adjusted mounting hole locations to fit on millimeter boundaries.
    [Chrismas_Tree.kicad_pcb]
2021-11-24 Rounded casing corners with the same radius than the PCB corners. Also adapted casing mounting holes to new PCB ones.
    [Casing_And_Parts.dxf]
2021-11-25 Added fiducials to PCB.
    [Chrismas_Tree.kicad_pcb, Chrismas_Tree.sch]
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
